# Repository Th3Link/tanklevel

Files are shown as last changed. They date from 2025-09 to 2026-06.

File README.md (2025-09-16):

# TL-136 Liquid Level Sensor

This project provides a solution for **measuring the liquid level in tanks**, such as rainwater tanks, using the **TL-136 pressure sensor**. It is designed for **easy integration with home automation systems**, connecting via **Wi-Fi** or **Ethernet**.

## Features

- Measures liquid levels in tanks accurately using the TL-136 sensor.  
- Connectivity: Wi-Fi or Ethernet for integration with smart home systems.  
- Compact design to fit in a **3-way IP68 junction box** (minimum inner dimensions: 90 × 110 mm).  
- PCB target size: 80 × 60 mm.  
- Powered by a **24V supply**, e.g., MEAN WELL APV-8-24 (8W).  

## Inspiration

This project is **heavily inspired** by:  
[Nachbelichtet – Measuring Water Levels in Cisterns with Home Assistant, ESPHome, and TL-136](https://nachbelichtet.com/wasserstand-in-zisternen-mit-homeassistant-esphome-und-tl-136-drucksensor-messen)

## License

This project is licensed under the **CERN Open Hardware License – Strongly Reciprocal (CERN OHL-S)**.  
See [`LICENSE.txt`](LICENSE.txt) for details.

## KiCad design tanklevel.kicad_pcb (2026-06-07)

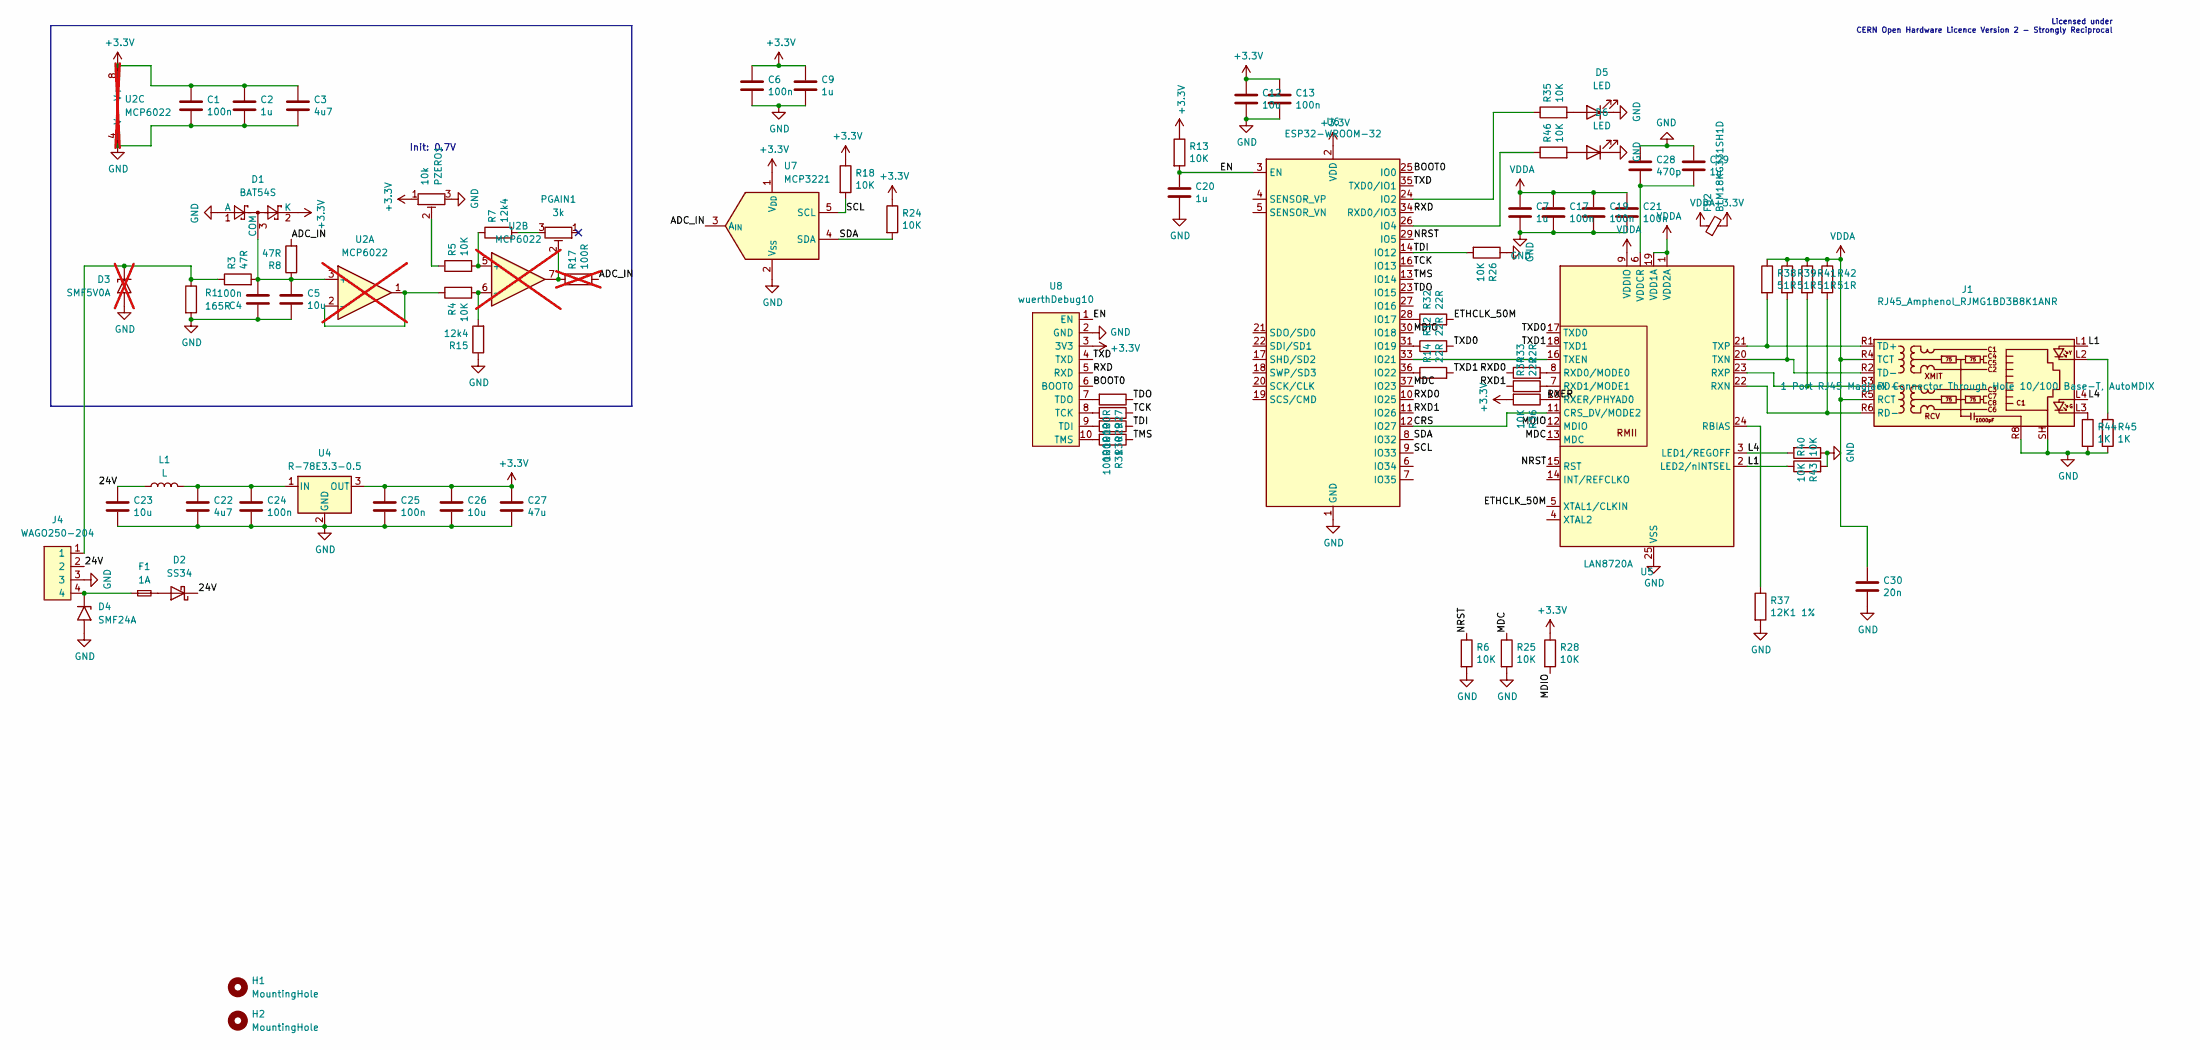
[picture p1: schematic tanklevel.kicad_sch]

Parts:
C1, C4, C6, C13, C17, C19, C21, C24, C25: 100n; C_0603_1608Metric_Pad1.08x0.95mm_HandSolder; LCSC PN C14663
C2, C7, C9, C20, C29: 1u; C_0805_2012Metric_Pad1.18x1.45mm_HandSolder; LCSC PN C28323
C3: 4u7; C_0805_2012Metric_Pad1.18x1.45mm_HandSolder; LCSC PN C1779
C5, C12, C26: 10u; C_0805_2012Metric_Pad1.18x1.45mm_HandSolder; LCSC PN C15850
C22: 4u7; C_1206_3216Metric_Pad1.33x1.80mm_HandSolder; LCSC PN C51205
C23: 10u; C_1206_3216Metric_Pad1.33x1.80mm_HandSolder; LCSC PN C13585
C27: 47u; C_1210_3225Metric_Pad1.33x2.70mm_HandSolder; LCSC PN C77101
C28: 470p; C_0603_1608Metric_Pad1.08x0.95mm_HandSolder; LCSC PN C85979
C30: 20n; C_0603_1608Metric_Pad1.08x0.95mm_HandSolder; LCSC PN C282065
D1: BAT54S; SOT-23; LCSC PN C7420333
D2: SS34; D_SMA; LCSC PN C8678
D3: SMF5V0A; D_SMF; LCSC PN C19077497; not fitted
D4: SMF24A; D_SMF; LCSC PN C19077514
D5, D6: LED; LED_0603_1608Metric_Pad1.05x0.95mm_HandSolder; LCSC PN C157741
F1: 1A; Fuse_0603_1608Metric_Pad1.05x0.95mm_HandSolder; LCSC PN C151139
FB2: BLM18KG331SH1D; L_0603_1608Metric_Pad1.05x0.95mm_HandSolder; LCSC PN C710376
H1, H2: MountingHole; MountingHole_2.2mm_M2_DIN965
J1: RJ45_Amphenol_RJMG1BD3B8K1ANR
J4: WAGO250-204
L1: L; RLS-126-R
PGAIN1: 3k; Potentiometer_Bourns_3296W_Vertical
PZERO1: 10k; Potentiometer_Bourns_3296W_Vertical
R1: 165R; R_1206_3216Metric_Pad1.30x1.75mm_HandSolder; LCSC PN C870446
R3, R8: 47R; R_0603_1608Metric_Pad0.98x0.95mm_HandSolder; LCSC PN C114623
R4, R5, R6, R13, R18, R24, R25, R26, R28, R35, R36, R40, R43, R46: 10K; R_0603_1608Metric_Pad0.98x0.95mm_HandSolder; LCSC PN C140867
R7, R15: 12k4; R_0603_1608Metric_Pad0.98x0.95mm_HandSolder; LCSC PN C137798
R12, R14, R32, R33, R34: 22R; R_0603_1608Metric_Pad0.98x0.95mm_HandSolder; LCSC PN C138283
R17: 100R; R_0603_1608Metric_Pad0.98x0.95mm_HandSolder; LCSC PN C122970; not fitted
R27, R29, R30, R31: 100R; R_0603_1608Metric_Pad0.98x0.95mm_HandSolder; LCSC PN C122970
R37: 12K1 1%; R_0603_1608Metric_Pad0.98x0.95mm_HandSolder; LCSC PN C245906
R38, R39, R41, R42: 51R; R_0603_1608Metric_Pad0.98x0.95mm_HandSolder; LCSC PN C23197
R44, R45: 1K; R_0603_1608Metric_Pad0.98x0.95mm_HandSolder; LCSC PN C22548
U2: MCP6022; SOIC-8_3.9x4.9mm_P1.27mm; LCSC PN C57639; not fitted
U4: R-78E3.3-0.5; Converter_DCDC_RECOM_R-78E-0.5_THT
U5: LAN8720A; QFN-24-1EP_4x4mm_P0.5mm_EP2.6x2.6mm; LCSC PN C45223
U6: ESP32-WROOM-32; LCSC PN C701341
U7: MCP3221; SOT-23-5; LCSC PN C36310
U8: wuerthDebug10; wuerth10

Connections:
+3.3V: C1.1, C2.1, C3.1, C6.1, C9.1, C12.1, C13.1, C25.1, C26.1, C27.1, D1.2 (K), FB2.2, PZERO1.1, R13.1, R18.1, R24.1, R28.1, R36.2, U2.8 (V+), U4.3 (OUT), U6.2 (VDD), U7.1 (V_{DD}), U8.3 (3V3)
/24V: C23.1, D2.1 (K), J4.2, L1.1
/ADC_IN: R8.2, R17.2, U7.3 (A_{IN})
/BOOT0: U6.25 (IO0), U8.6 (BOOT0)
/CRS: U5.11 (CRS_DV/MODE2), U6.12 (IO27)
/EN: C20.1, R13.2, U6.3 (EN), U8.1 (EN)
/ETHCLK_50M: R32.2, U5.5 (XTAL1/CLKIN)
/L1: J1.L1, R40.1, U5.2 (LED2/nINTSEL)
/L4: J1.L4, R43.2, U5.3 (LED1/REGOFF)
/MDC: R25.1, U5.13 (MDC), U6.37 (IO23)
/MDIO: R28.2, U5.12 (MDIO), U6.30 (IO18)
/NRST: R6.1, U5.15 (RST), U6.29 (IO5)
/RXD: U6.34 (RXD0/IO3), U8.5 (RXD)
/RXD0: R33.1, U6.10 (IO25)
/RXD1: R34.1, U6.11 (IO26)
/RXER: R36.1, U5.10 (RXER/PHYAD0)
/SCL: R18.2, U6.9 (IO33), U7.5 (SCL)
/SDA: R24.2, U6.8 (IO32), U7.4 (SDA)
/TCK: R29.1, U6.16 (IO13)
/TDI: R26.2, R30.1, U6.14 (IO12)
/TDO: R27.1, U6.23 (IO15)
/TMS: R31.1, U6.13 (IO14)
/TXD: U6.35 (TXD0/IO1), U8.4 (TXD)
/TXD0: R12.2, U5.17 (TXD0)
/TXD1: R14.2, U5.18 (TXD1)
GND: C1.2, C2.2, C3.2, C4.1, C5.2, C6.2, C7.2, C9.2, C12.2, C13.2, C17.2, C19.2, C20.2, C21.2, C22.2, C23.2, C24.2, C25.2, C26.2, C27.2, C28.1, C29.1, C30.2, D1.1 (A), D3.2 (A2), D4.2 (A2), D5.1 (K), D6.1 (K), J1.R8, J1.SH, J4.3, PZERO1.3, R1.2, R6.2, R15.1, R25.2, R26.1, R37.2, R40.2, R43.1, R44.2, R45.2, U2.4 (V-), U4.2 (GND), U5.25 (VSS), U6.1 (GND), U6.15 (GND), U6.38 (GND), U6.39 (GND), U7.2 (V_{SS}), U8.2 (GND)
unnamed: C4.2, C5.1, D1.3 (COM), R3.2, R8.1, U2.3 (+)
unnamed: D2.2 (A), F1.2
unnamed: D3.1 (A1), J4.1, R1.1, R3.1
unnamed: D4.1 (A1), F1.1, J4.4
unnamed: D5.2 (A), R35.2
unnamed: D6.2 (A), R46.2
unnamed: J1.L2, R45.1
unnamed: J1.L3, R44.1
unnamed: J1.R3 (RD+), R41.2, U5.23 (RXP)
unnamed: J1.R6 (RD-), R42.2, U5.22 (RXN)
unnamed: J1.R1 (TD+), R38.2, U5.21 (TXP)
unnamed: J1.R2 (TD-), R39.2, U5.20 (TXN)
unnamed: PGAIN1.2, R17.1, U2.7
unnamed: PGAIN1.3, R7.2
unnamed: PZERO1.2, R5.1
unnamed: R4.1, U2.1, U2.2 (-)
unnamed: R5.2, R7.1, U2.5 (+)
unnamed: R4.2, R15.2, U2.6 (-)
unnamed: C22.1, C24.1, L1.2, U4.1 (IN)
unnamed: R37.1, U5.24 (RBIAS)
unnamed: R33.2, U5.8 (RXD0/MODE0)
unnamed: R34.2, U5.7 (RXD1/MODE1)
unnamed: U5.16 (TXEN), U6.33 (IO21)
unnamed: C28.2, C29.2, U5.6 (VDDCR)
unnamed: R35.1, U6.24 (IO2)
unnamed: R46.1, U6.26 (IO4)
unnamed: R32.1, U6.28 (IO17)
unnamed: R12.1, U6.31 (IO19)
unnamed: R14.1, U6.36 (IO22)
unnamed: R29.2, U8.8 (TCK)
unnamed: R30.2, U8.9 (TDI)
unnamed: R27.2, U8.7 (TDO)
unnamed: R31.2, U8.10 (TMS)
VDDA: C7.1, C17.1, C19.1, C21.1, C30.1, FB2.1, J1.R4 (TCT), J1.R5 (RCT), R38.1, R39.1, R41.1, R42.1, U5.1 (VDD2A), U5.9 (VDDIO), U5.19 (VDD1A)

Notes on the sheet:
Licensed under CERN Open Hardware Licence Version 2 - Strongly Reciprocal
Init: 0.7V

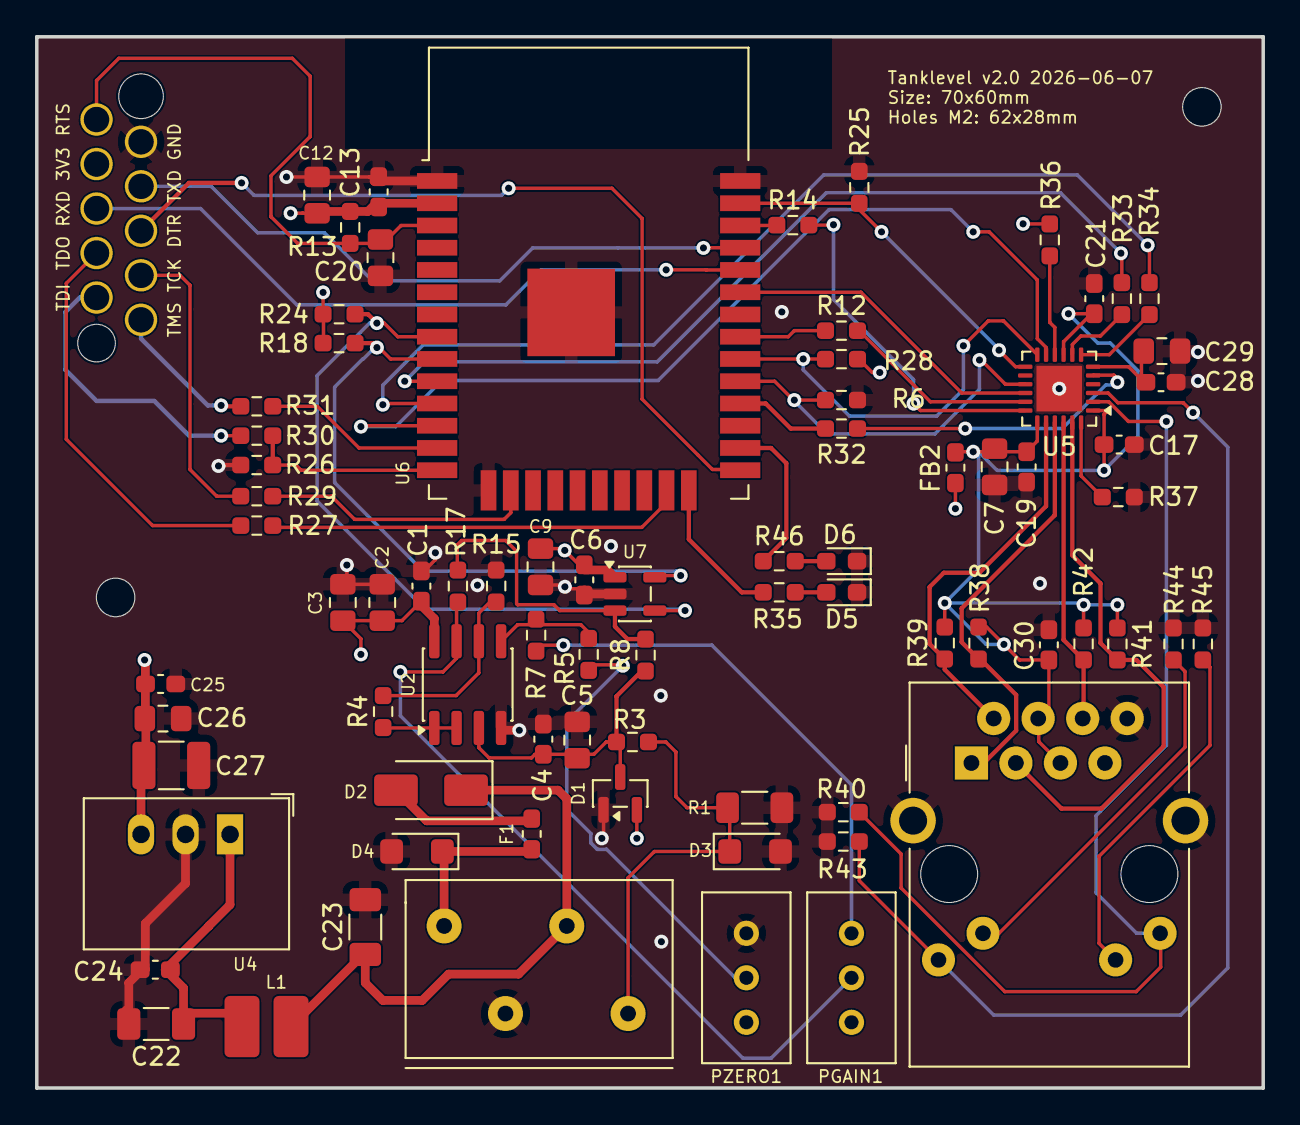
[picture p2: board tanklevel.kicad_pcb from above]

Board: 4 copper layers, 70.0 x 60.0 mm, 80 parts (0 on the bottom side), 60 nets.

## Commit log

2025-09-16 feat: Initial commit
    [tanklevel.kicad_pcb, tanklevel.kicad_sch]
2026-03-14 feat: Switch back to LAN8720A
    [tanklevel.kicad_pcb, tanklevel.kicad_sch]
2026-06-07 feat: Update to tanklevel v2 pcb
    [tanklevel.kicad_pcb, tanklevel.kicad_sch]
